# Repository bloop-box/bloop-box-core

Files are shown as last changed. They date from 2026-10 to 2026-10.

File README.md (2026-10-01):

# bloop-box-core



3D Render

[Hardware Documentation](https://bloop-box.github.io/bloop-box-core)

### !!! THIS IS A PROTOTYPE WORK IN PROGRESS !!!

## What does it do?

This board is supposed to replace the Raspberry Pi Zero 2W in the bloop box with a cheaper alternative, using an ESP32-C5.

It will support all functions of the bloop box and can be used as a drop-in-replacement for the Raspi. In addition, due to the capabilities of the ESP32-C5 this will have support for 5GHz WiFi.

## GPIO

| Function | ESP-Pin |
|:---|:---|
| Button1 (BOOT) | GPIO 28 |
| Button2 | GPIO 27 |
| LED1 | GPIO 25 |
| LED2 | GPIO 26 |
| I2C SCL | GPIO 3  |
| I2C SDA | GPIO 2  |
| I2S BCLK | GPIO 23 |
| I2S DIN | GPIO 4  |
| I2S LRCLK | GPIO 24 |
| SPI MISO | GPIO 9  |
| SPI MOSI | GPIO 8  |
| SPI SCK | GPIO 6  |
| NFC CS | GPIO 10 |
| NFC IRQ | GPIO 0  |
| NFC RST | GPIO 1  |
| SD CS | GPIO 5  |
| SD Detect | GPIO 7  |
| Serial RX | GPIO 12 |
| Serial TX | GPIO 11 |

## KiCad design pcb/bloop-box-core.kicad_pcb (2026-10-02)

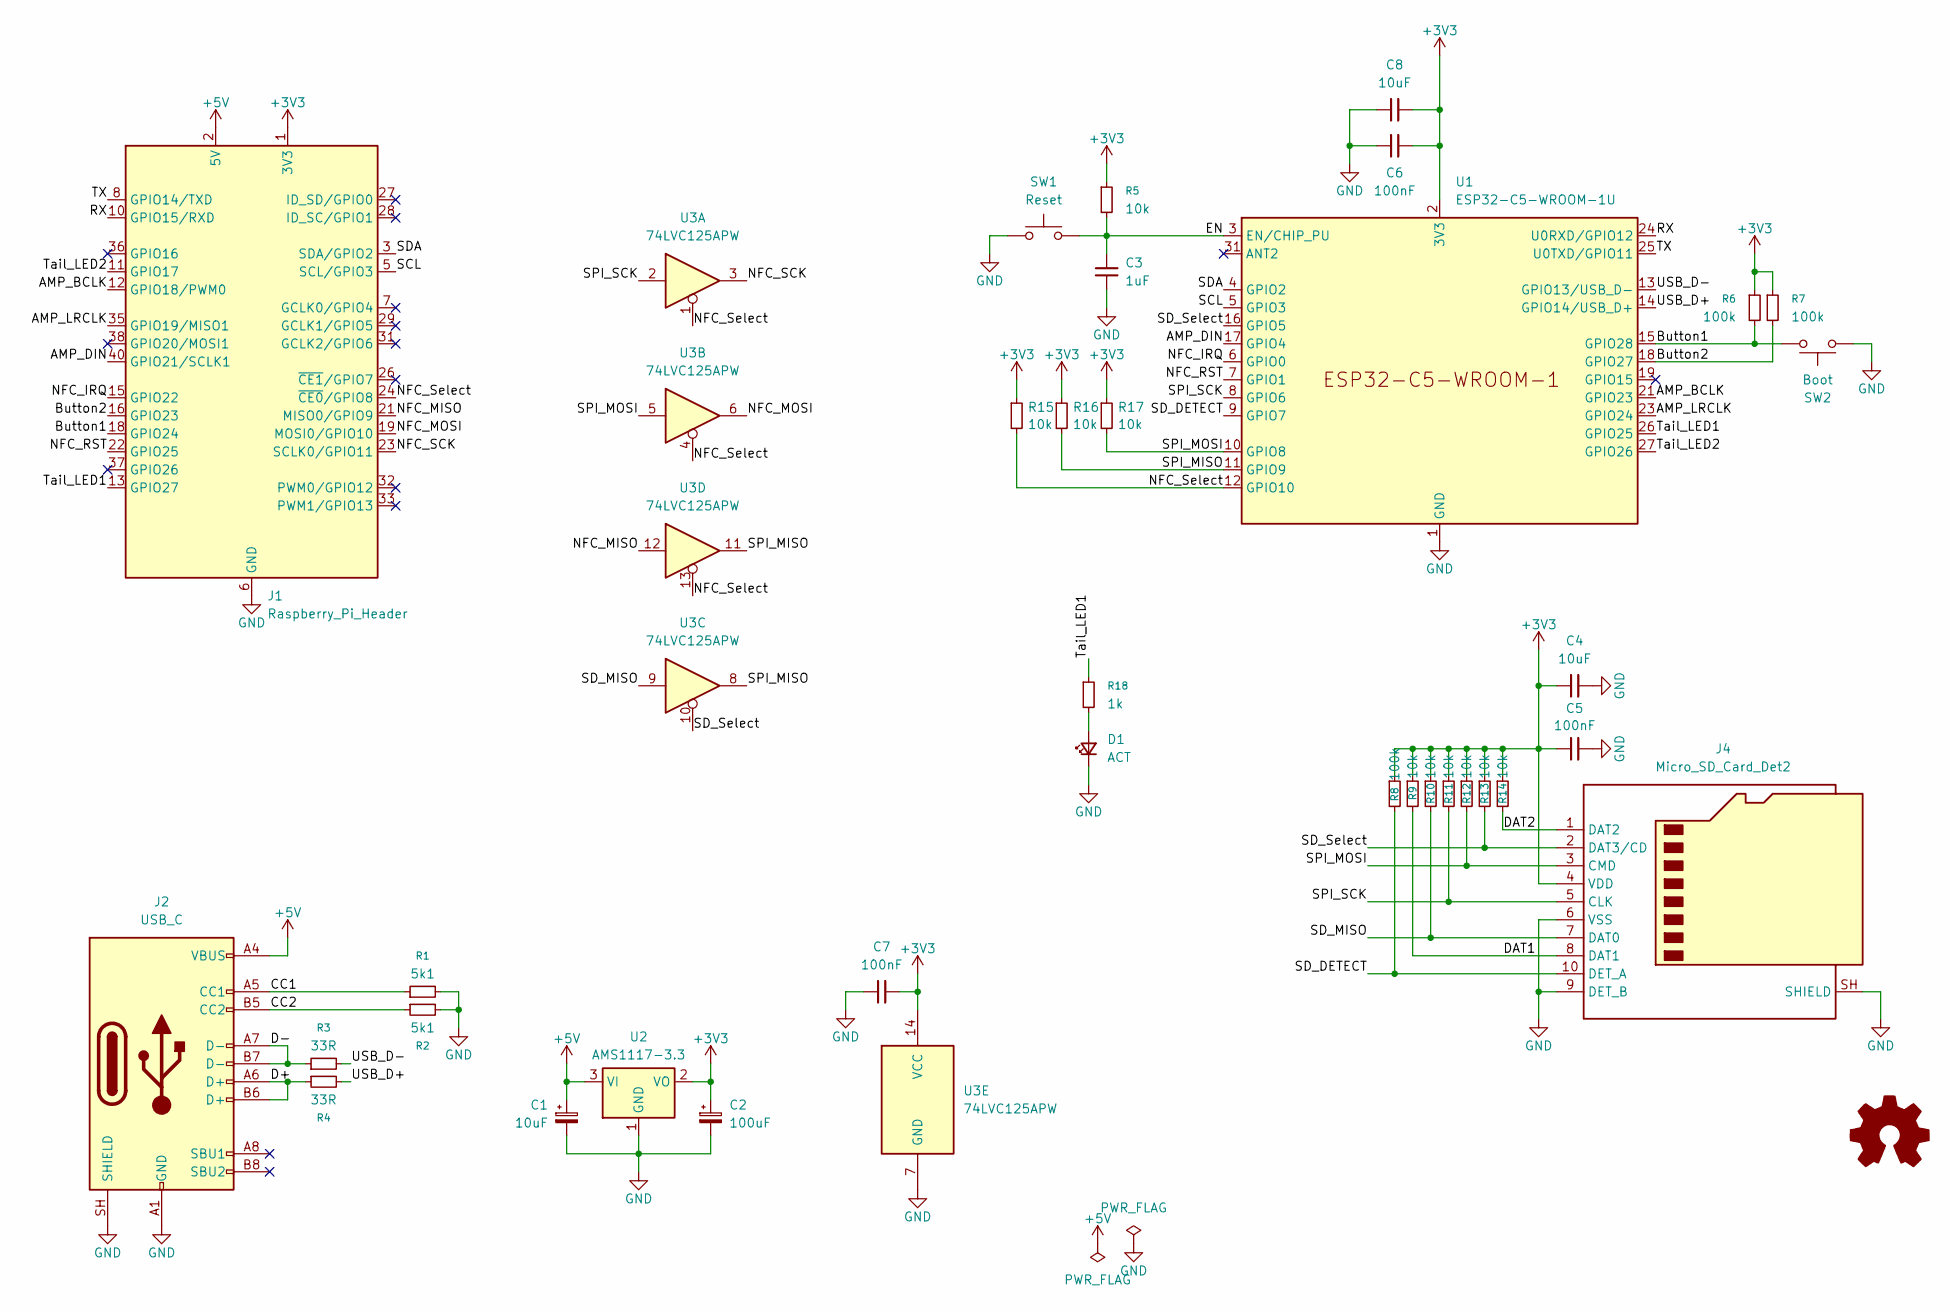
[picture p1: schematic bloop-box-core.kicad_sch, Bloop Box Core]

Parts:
C1: 10uF; CP_EIA-3216-18_Kemet-A; LCSC C7171
C2: 100uF; CP_EIA-3528-21_Kemet-B; LCSC C16133
C3: 1uF; C_0402_1005Metric; LCSC C52923
C4, C8: 10uF; C_0402_1005Metric; LCSC C15525
C5, C6, C7: 100nF; C_0402_1005Metric; LCSC C1525
D1: ACT; LED_0603_1608Metric; LCSC C89811
J1: Raspberry_Pi_Header; PinHeader_2x20_P2.54mm_Vertical; LCSC C50980
J2: USB_C; USB_C_Receptacle_GCT_USB4105-xx-A_16P_TopMnt_Horizontal; LCSC C2765186
J4: Micro_SD_Card_Det2; microSD_HC_Molex_104031-0811; LCSC C585350
R1, R2: 5k1; R_0402_1005Metric; LCSC C25905
R3, R4: 33R; R_0402_1005Metric; LCSC C25105
R5, R9, R10, R11, R12, R13, R14, R15, R16, R17: 10k; R_0402_1005Metric; LCSC C25744
R6, R7, R8: 100k; R_0402_1005Metric; LCSC C25741
R18: 1k; R_0402_1005Metric; LCSC C11702
SW1: Reset; SW_Push_SPST_NO_Alps_SKRK; LCSC C720477
SW2: Boot; SW_Push_SPST_NO_Alps_SKRK; LCSC C720477
U1: ESP32-C5-WROOM-1U; LCSC C54951857
U2: AMS1117-3.3; SOT-223-3_TabPin2; LCSC C6186
U3: 74LVC125APW; TSSOP-14_4.4x5mm_P0.65mm; LCSC C6059

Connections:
+3V3: C2.1, C4.2, C5.2, C6.2, C7.2, C8.1, J1.1 (3V3), J1.17 (3V3), J4.4 (VDD), R5.1, R6.1, R7.1, R8.1, R9.1, R10.1, R11.1, R12.1, R13.1, R14.1, R15.1, R16.1, R17.1, U1.2 (3V3), U2.2 (VO), U3.14 (VCC)
+5V: C1.1, J1.2 (5V), J1.4 (5V), J2.A4 (VBUS), J2.A9 (VBUS), J2.B4 (VBUS), J2.B9 (VBUS), U2.3 (VI)
/AMP_BCLK: J1.12 (GPIO18/PWM0), U1.21 (GPIO23)
/AMP_DIN: J1.40 (GPIO21/SCLK1), U1.17 (GPIO4)
/AMP_LRCLK: J1.35 (GPIO19/MISO1), U1.23 (GPIO24)
/Button1: J1.18 (GPIO24), R6.2, SW2.1, U1.15 (GPIO28)
/Button2: J1.16 (GPIO23), R7.2, U1.18 (GPIO27)
/CC1: J2.A5 (CC1), R1.1
/CC2: J2.B5 (CC2), R2.1
/D+: J2.A6 (D+), J2.B6 (D+), R4.1
/D-: J2.A7 (D-), J2.B7 (D-), R3.1
/DAT1: J4.8 (DAT1), R9.2
/DAT2: J4.1 (DAT2), R14.2
/EN: C3.1, R5.2, SW1.2, U1.3 (EN/CHIP_PU)
/NFC_IRQ: J1.15 (GPIO22), U1.6 (GPIO0)
/NFC_MISO: J1.21 (MISO0/GPIO9), U3.12
/NFC_MOSI: J1.19 (MOSI0/GPIO10), U3.6
/NFC_RST: J1.22 (GPIO25), U1.7 (GPIO1)
/NFC_SCK: J1.23 (SCLK0/GPIO11), U3.3
/NFC_Select: J1.24 (~CE0/GPIO8), R15.2, U1.12 (GPIO10), U3.1, U3.4, U3.13
/RX: J1.10 (GPIO15/RXD), U1.24 (U0RXD/GPIO12)
/SCL: J1.5 (SCL/GPIO3), U1.5 (GPIO3)
/SDA: J1.3 (SDA/GPIO2), U1.4 (GPIO2)
/SD_DETECT: J4.10 (DET_A), R8.2, U1.9 (GPIO7)
/SD_MISO: J4.7 (DAT0), R10.2, U3.9
/SD_Select: J4.2 (DAT3/CD), R13.2, U1.16 (GPIO5), U3.10
/SPI_MISO: R16.2, U1.11 (GPIO9), U3.8, U3.11
/SPI_MOSI: J4.3 (CMD), R12.2, R17.2, U1.10 (GPIO8), U3.5
/SPI_SCK: J4.5 (CLK), R11.2, U1.8 (GPIO6), U3.2
/TX: J1.8 (GPIO14/TXD), U1.25 (U0TXD/GPIO11)
/Tail_LED1: J1.13 (GPIO27), R18.1, U1.26 (GPIO25)
/Tail_LED2: J1.11 (GPIO17), U1.27 (GPIO26)
/USB_D+: R4.2, U1.14 (GPIO14/USB_D+)
/USB_D-: R3.2, U1.13 (GPIO13/USB_D-)
GND: C1.2, C2.2, C3.2, C4.1, C5.1, C6.1, C7.1, C8.2, D1.1 (K), J1.6 (GND), J1.9 (GND), J1.14 (GND), J1.20 (GND), J1.25 (GND), J1.30 (GND), J1.34 (GND), J1.39 (GND), J2.A1 (GND), J2.A12 (GND), J2.B1 (GND), J2.B12 (GND), J2.SH (SHIELD), J4.6 (VSS), J4.9 (DET_B), J4.SH (SHIELD), R1.2, R2.2, SW1.1, SW2.2, U1.1 (GND), U1.28 (GND), U1.29 (GND), U1.30 (GND), U1.32 (GND), U2.1 (GND), U3.7 (GND)
unnamed: D1.2 (A), R18.2

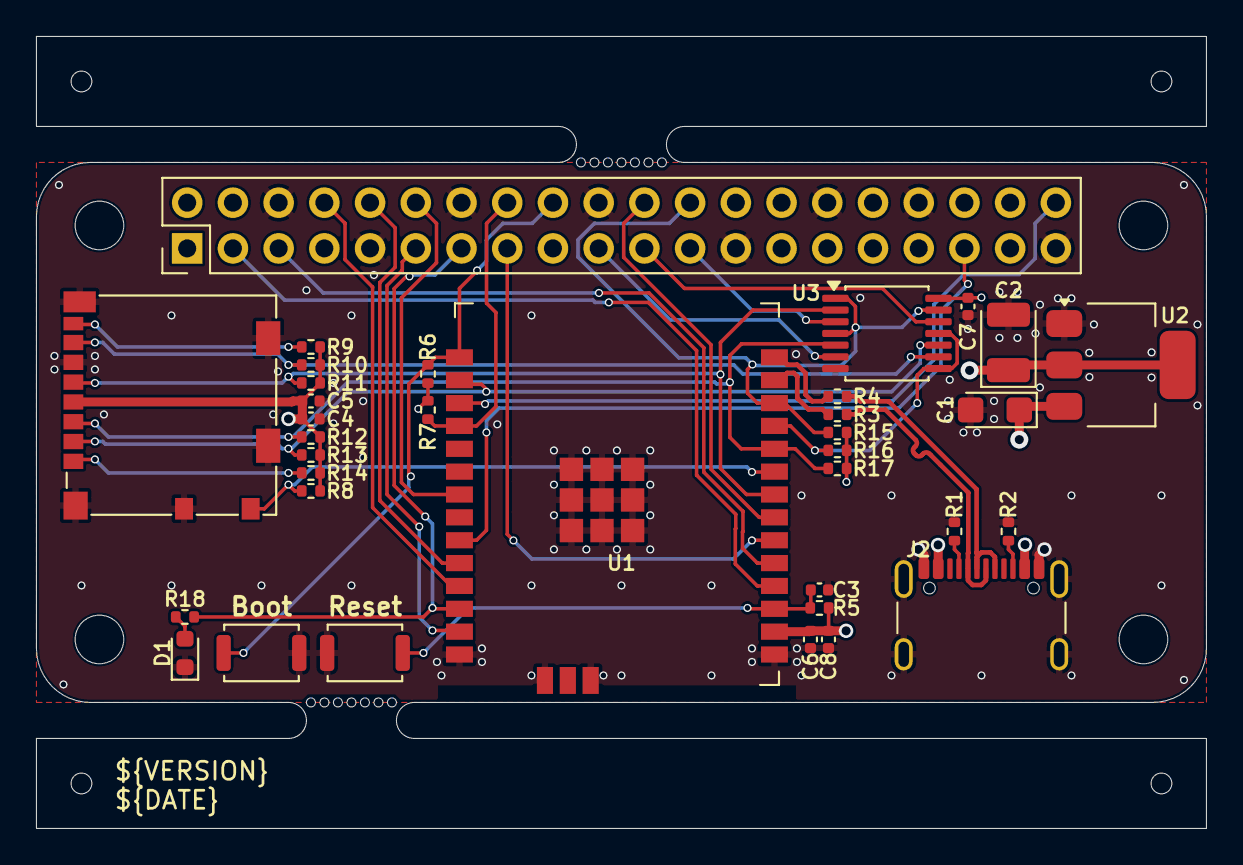
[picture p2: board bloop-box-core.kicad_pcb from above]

Board: 4 copper layers, 65.0 x 44.0 mm, 37 parts (0 on the bottom side), 36 nets.

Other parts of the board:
mouse-bite-2mm-slot, mouse-bite-2mm-slot#2: VAL**; mouse-bite-2x5mm-slot-onesided-v2

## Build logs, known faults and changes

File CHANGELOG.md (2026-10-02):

# Changelog

## 1.0.0 (2026-10-02)

### Features

* add detect pin for SD-Card ([524aee3](https://github.com/bloop-box/bloop-box-core/commit/524aee37b8fab22b780b515963a676dcb813a1c7))
* add edge rails ([6d3d480](https://github.com/bloop-box/bloop-box-core/commit/6d3d4806bf3b7f63c2da6b39f513ace858daeb76))
* bottom silkscreen ([524aee3](https://github.com/bloop-box/bloop-box-core/commit/524aee37b8fab22b780b515963a676dcb813a1c7))
* Initial commit ([39a21cf](https://github.com/bloop-box/bloop-box-core/commit/39a21cfff52d53a4dd36b0566866d85fecf835c2))
* trace-routing ([cc64d38](https://github.com/bloop-box/bloop-box-core/commit/cc64d38c92604b80be1f83b9de7a9943bda093f5))

### Bug Fixes

* capacitor values ([a5d7828](https://github.com/bloop-box/bloop-box-core/commit/a5d78283a1c10914f69c485497729124f3c60aa8))

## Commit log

2026-10-01 feat: Initial commit
    Still under development...
    [bloop-box-core.kicad_pcb, bloop-box-core.kicad_sch]
2026-10-01 feat: trace-routing
    All traces are routed
    [bloop-box-core.kicad_pcb, bloop-box-core.kicad_sch]
2026-10-01 feat: add detect pin for SD-Card
    connect SD-Detect to IO7
    feat: bottom silkscreen
    [bloop-box-core.kicad_pcb, bloop-box-core.kicad_sch]
2026-10-01 feat: add edge rails
    [bloop-box-core.kicad_pcb, bloop-box-core.kicad_sch]
2026-10-02 fix: capacitor values
    [bloop-box-core.kicad_pcb, bloop-box-core.kicad_sch]
